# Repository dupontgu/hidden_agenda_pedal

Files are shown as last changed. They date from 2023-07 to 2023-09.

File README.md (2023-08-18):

# Hidden Agenda
 **A multi-effects pedal for your mouse and keyboard!**

 Have you ever wanted to add reverb to your mouse cursor and sending sailing gently accross your screen? Have you ever wished you could emphatically stomp on something to engage caps lock before ripping an angry email to your manager or tweeting at an airline? No? Well, I made this anyways.

 YouTube Thumbnail (https://www.youtube.com/watch?v=4DGEuZlxPWg)

 ## Contents
 * [How it works](#how-it-works) (at a high level)
 * [Full usage instructions](.docs/usage/)
 * [FAQ](.docs/faq/)
 * [Firmware Source Code](firmware/) (and build instructions)
 * [Electronics](hardware/) (schematic/board files)
 * [Enclosure](enclosure/) (CAD/Art)
 * [Alternate Usages](./circuitpython/) (use it as a MIDI controller!!)

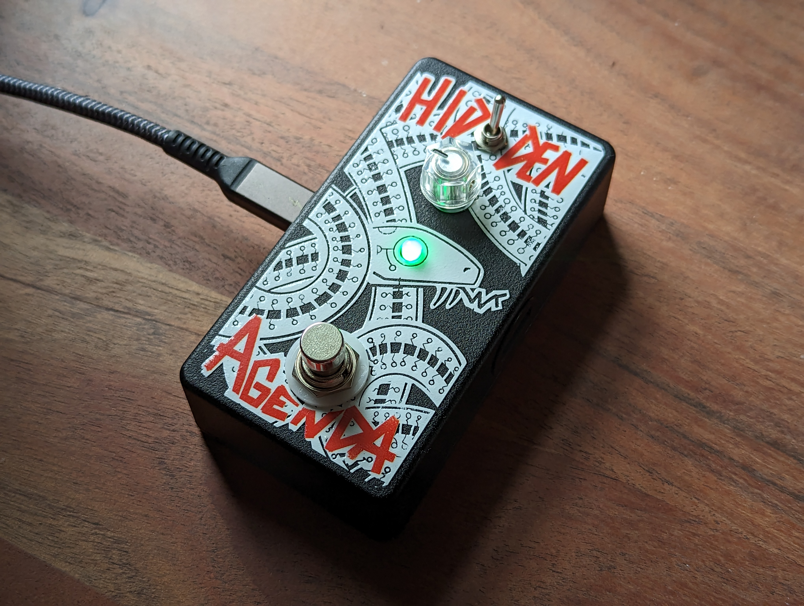
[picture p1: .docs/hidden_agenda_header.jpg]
 [](.docs/hidden_agenda_header.jpg)

 ### Shout-outs
 * Pedal artwork by [Ted Pioli](https://www.tedp.io/)
 * Pedal fabrication from [AmplifyFUN](https://amplifyfun.com/)

 ## How It Works

 The Hidden Agenda works as an HID interceptor. You plug your mouse/keyboard directly into the pedal, and then you plug the pedal into your computer via USB. The software on the pedal analyzes the data coming from the keyboard/mouse, applies some "signal processing" to it, and then forwards the processed data to the computer. When the pedal is off, it simply passes the keyboard/mouse data through without modifying it. It is a standalone unit and should not require any additional software to be installed on your computer - as far as it's concerned, the pedal is just a run-of-the-mill USB keyboard/mouse combo.

 ## What Effects Does It Have?

 The Hidden Agenda currently has 4 unique effects for mouse, and 4 for keyboard. They are mostly inspired by classic audio effects that you might find in a "real" pedal. Each effect has one parameter that can be tweaked with the onboard knob.

 ### Mouse Effects
 #### `1. Reverb`
 Send your cursor flying! This effect adds a bit of momentum to your mouse cursor, so when you stop moving your hand, it will keep going in the direction you were heading. When this effect is active, the knob controls the "length" of the reverb (or, how long it will take to slow down to a stop after you've stopped moving).

 #### `2. Looper`
 Record a gesture with your mouse and play it back on a loop. Hold the right mouse button down to record, move around as you please, and watch loop playback begin as soon as you release. Use the knob to adjust the playback speed of the loop. Turn it all the way up to play it at 2.5X speed, turn it all the way down to play at -2.5X (reversed!).

 #### `3. Distortion / Noise Filter`
 This is a two-in-one effect. Turn _up_ the knob (past halfway), and the pedal will add an increasing amount of random noise to your path of motion. Turn _down_ the knob, and the pedal will apply a low-pass filter to your motion, effectively smoothing it out. 

 #### `4. (Bonus) Crossover`
 Use your mouse as a keyboard! Use the scroll wheel to choose between characters, then tap the right mouse button to move on to the next. Hold the left mouse button + move left to backspace, move right to enter spaces, or move down to "hit" enter. You can also hold the right mouse button and move up/down to scroll through characters. The knob controls the speed at which the characters scroll.

 ### Keyboard Effects
 #### `1. Tremolo`
 Change the "volume" of your typing on a time interval. Imagine an imaginary hand pressing and releasing the shift key for you on a fixed schedule. Turn the knob up to increase the switch rate between upper/lowercase. If you turn the knob _all_ the way up, the effect will constanly force your typing to uppercase, effectively turning the pedal into a foot-powered caps lock button. If you turn the knob all the way down, the pedal will apply rANdOm/SarCaStiC case as you type.

 #### `2. Delay`
 Echo! (echo... echo...). This effect will repeat keystrokes on a time interval for you while it is engaged. The knob is divided into 4 zones, each corresponding to a delay interval time (from left to right: short, short-ish, long-ish, long). Within each zone, the knob controls the "feedback" - AKA the number of repetitions for a given keystroke. The rightmost edge of each zone will set the delay to repeat infinitely for maximum of 6 keys.

 #### `3. Pitch Shift / Harmonizer`
 Maps your keystrokes to... different keystrokes. The knob is divided into 3 sections. In the lowest section, the pedal will simply replace the keys you're pressing with those which are a fixed _"distance"_ away (by their [ascii number](https://www.asciitable.com/)). So if the distance is set to 1, and you press the 'a' key, the pedal will instead type 'b'. If the distance is set to 2, pressing 'a' would yield 'c', etc. You can increase the distance between characters by turning the knob up. As soon as you turn the knob into the second section (about 10 o'clock), the behavior changes slightly. Now, instead of a "pitch shift", this becomes a "harmony" - the orignal key you pressed will be typed, _as well as_ the shifted one. In other words, pressing one key will yield two typed characters. If you turn the knob into the third section (about 2 o'clock), the pedal will type 3 characters for each key you press: your original key character, one that is `n` characters away from that one, and another that is `n` characters away from the second. Think of it as a chord! You can turn up the knob _within_ each section to increase `n`.

 #### `4. (Bonus) Crossover`
 Use your keyboard as a mouse! The arrow keys move the cursor as you'd expect. The `enter` key emulates the mouse's left button. Use the letter keys to send the cursor flying in random directions. Yes, seriously. Modifier keys work as usual.

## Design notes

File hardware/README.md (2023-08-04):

# Hidden Agenda Hardware

Check out an interactive version of this KiCAD project using [KiCanvas](https://kicanvas.org/?github=https://github.com/dupontgu/hidden_agenda_pedal/tree/main/hardware)!!

## BOM

_Most_ of the BOM is available in a [DigiKey parts list](https://www.digikey.com/en/mylists/list/27DUQKO28G), but please read the following notes:
* I have been purchasing the [potentiometer](https://guitarpedalparts.com/products/b5k-16mm-potentiometer-round-shaft-right-angle-pcb-pins), 
[SPDT toggle switch](https://guitarpedalparts.com/products/spdt-on-off-on-toggle-switch-solder-lugs), 
[footswitch](https://guitarpedalparts.com/products/momentary-spdt-foot-switch), and 
[knob cap](https://guitarpedalparts.com/products/small-fluted-knob-clear) on [GuitarPedalParts.com](https://guitarpedalparts.com/)
* For the LED, I use the [WS2812D-F5](https://datasheet.lcsc.com/lcsc/2204181500_Worldsemi-WS2812D-F5_C190565.pdf), which runs on 3.3V power and logic. These are easily sourced on eBay/AliExpress.

## USB Jack Caps

The [USB Jack Caps](./usb_caps_v6.stl) are 3D printed. I use a black, recycled PETG. They push into the side holes on the pedal and stabilize the USB ports (the whole PCB, really). They screw directly into the threaded inserts on the PCB using standard 8mm M3 screws.

## Assembly Notes

* All components are through-hole except for the XIAO RP2040 module.
* The boot button should be installed on the _bottom_ of the board.
* The threaded inserts should also be inserted and soldered from the bottom of the board. For safety, I have been taping over the holes on the top side as well.

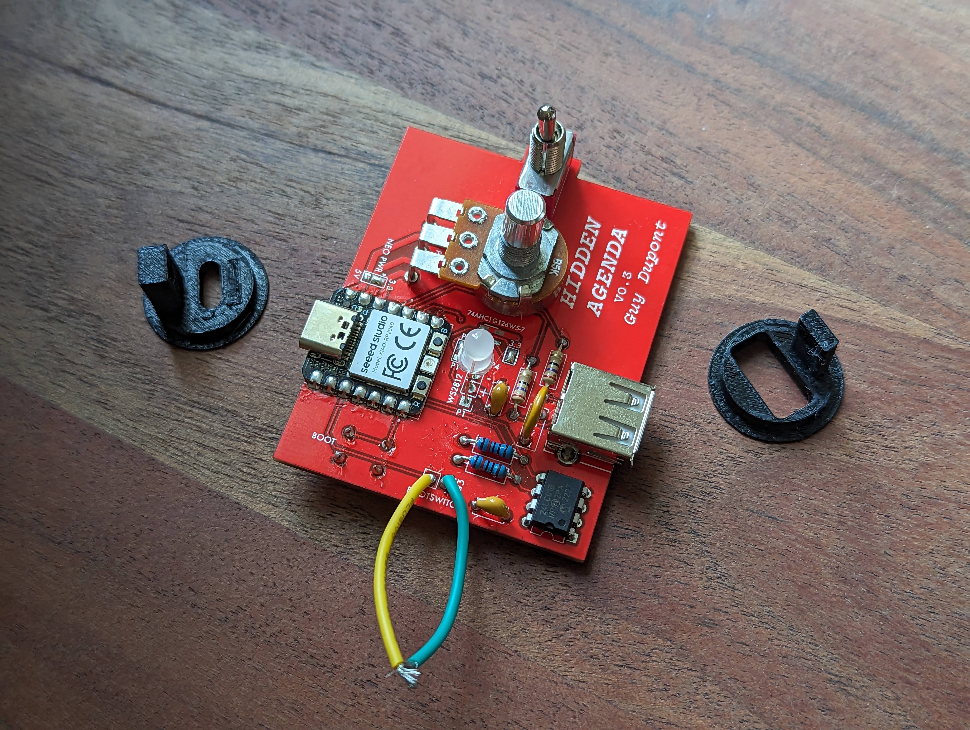
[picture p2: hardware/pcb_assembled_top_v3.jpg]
 [](./pcb_assembled_top_v3.jpg)
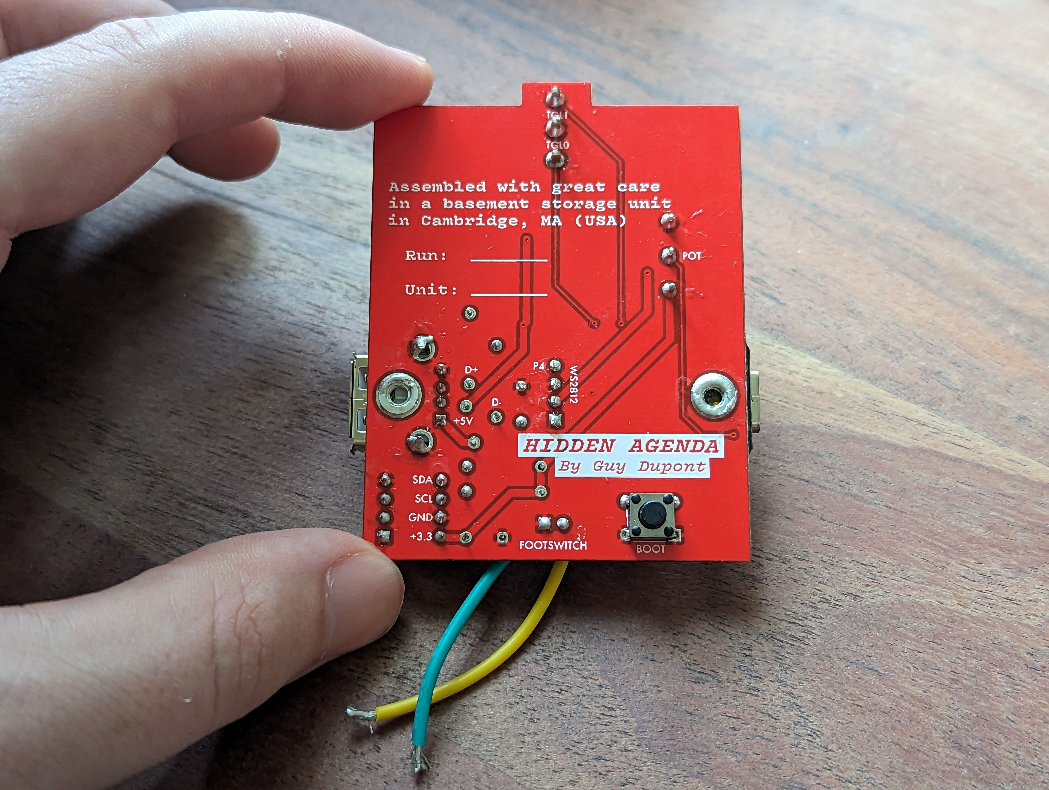
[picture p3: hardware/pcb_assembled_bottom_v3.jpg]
 [](./pcb_assembled_bottom_v3.jpg)

## Schematic

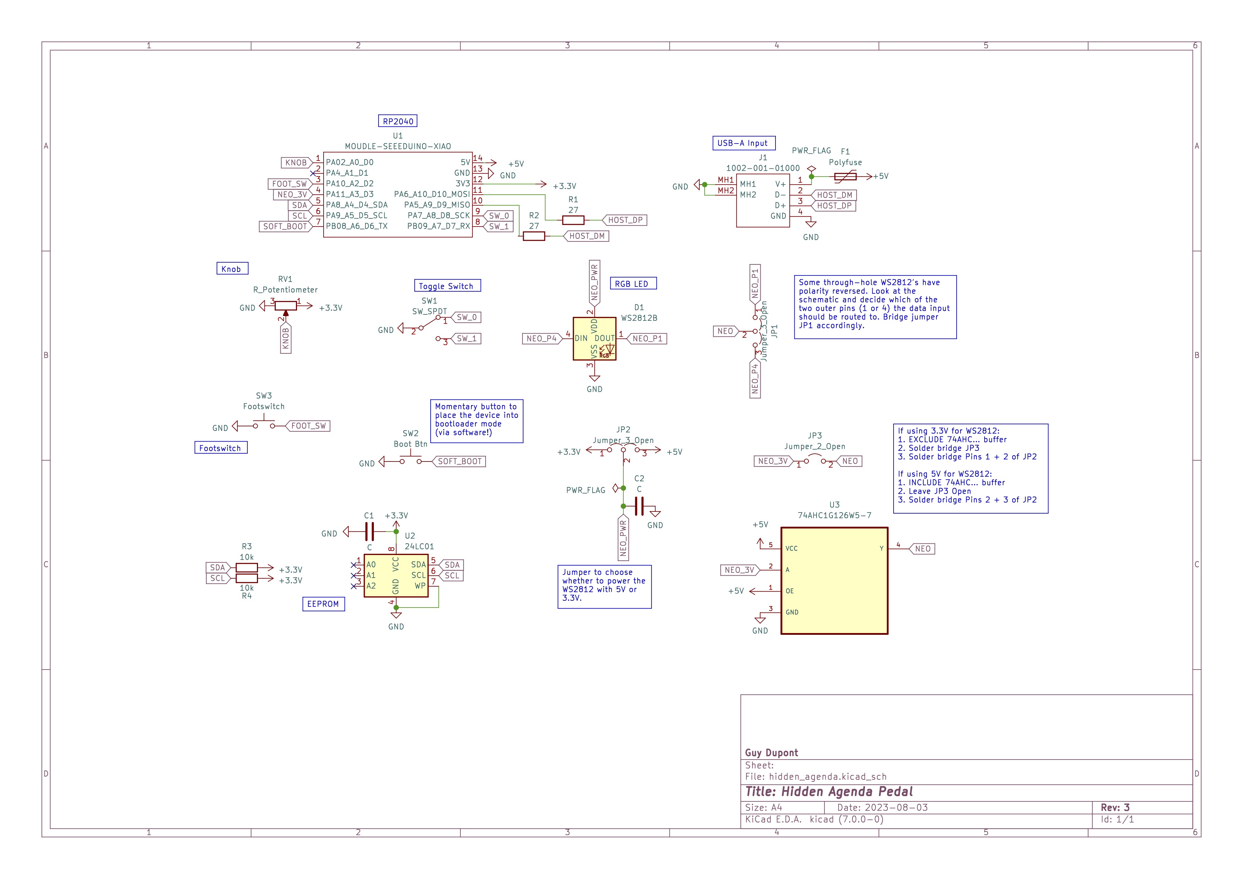
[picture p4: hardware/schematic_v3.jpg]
 [](./schematic_v3.pdf)

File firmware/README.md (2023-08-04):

# Hidden Agenda Firmware
* The pedal is built around the [Raspberry Pi RP2040](https://www.raspberrypi.com/documentation/microcontrollers/rp2040.html) microcontroller.
* The firmware is written in C/C++, using the [Raspberry Pi Pico SDK](https://github.com/raspberrypi/pico-sdk).
* It leverages the [Pico PIO USB](https://github.com/sekigon-gonnoc/Pico-PIO-USB) library, which gives the RP2040 an extra (bit-banged) USB port.
* See the [hardware](../hardware/) section to match up pin numbers.

## Building (Linux)
1. Ensure CMAKE is installed.
1. Clone the Pico SDK and all of its submodules. Export the SDK's path to an environment variable called `PICO_SDK_PATH`.
1. Clone the Pico PIO USB library. Export the library's path to an environment variable called `PICO_PIO_USB_DIR`.
1. Clone this repository, `cd` into the `firmware` directory.
1. Create a build directory and use `cmake` to configure the build:
    ```
    $ mkdir build && cd build
    $ cmake -DPICO_BOARD=ha_board ..
    ```
1. Run the build (you can run this step without the previous ones from here on out):
    ```
    $ make
    ```
1. Find the compiled UF2 file at `build/src/hidden_agenda.uf2` - this can loaded onto the RP2040 while it is in USB bootloader mode.

## Running Tests (Any Platform?)
Code in the [`common`](common) directory should be platform agnostic. Therefore it is possible to run tests against this code on your build machine. The `test` directory will contain an executable that runs default tests. To build this executable, follow the steps above, but add the `TEST` flag when running cmake:
```
cmake -DTEST=ON ..
```
If you've previously built the firmware, you'll have to delete the `CMakeCache.txt` file in the build directory. You'll have to delete this each time you change the `TEST` flag.

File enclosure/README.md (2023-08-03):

# Hidden Agenda Enclosure

 * Pedal artwork by [Ted Pioli](https://www.tedp.io/)
 * Pedal fabrication from [AmplifyFUN](https://amplifyfun.com/)
   * The .psd file in this directory is AmplifyFUN's template file for a 1590B pedal enclosure, populated with the artwork and drill marks for the Hidden Agenda.

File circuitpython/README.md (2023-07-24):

# Hidden Agenda CircuitPython
## Contents
* [How to use the Hidden Agenda as a MIDI controller](./midi_controller/)
* [CircuitPython test script used during board bring-up](./test_script/)

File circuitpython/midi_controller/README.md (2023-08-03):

## Using the Hidden Agenda as a MIDI Controller
**IMPORTANT! This will overwrite the default firmware on your pedal! You will need to [reinstall](../../.docs/usage/README.md#boot-button-updatemodify-the-firmware) it to regain normal functionality.**

The MIDI controller firmware was implemented in [CircuitPython](https://www.circuitpython.org), which makes it super easy to install and customize!

## Installation
1. On your computer, download the latest CircuitPython 8 [UF2 file for the `Seeed Studio XIAO RP2040`](https://circuitpython.org/board/seeeduino_xiao_rp2040/) (That's the microcontroller board that powers this pedal!)
2. Download a recent version of the [Adafruit MIDI library (for Circuitpython 8)](https://github.com/adafruit/Adafruit_CircuitPython_MIDI/releases/download/1.4.16/adafruit-circuitpython-midi-8.x-mpy-1.4.16.zip).
3. Download the `code.py` file from this directory.
4. Unscrew and remove the bottem panel of your pedal.
5. Plug the pedal into your computer using the USB-C port.
6. Press and release the "Boot" button on the inside (bottom) of the pedal. You'll need to unscrew/remove the bottom panel.
7. Observe that the pedal is now mounted as a disk drive on your computer (It will likely be called `RPI-RP2`).
8. Drag/drop the UF2 file you downloaded in step 1 onto the new disk drive. The pedal should reboot and remount as a drive called `CIRCUITPY`.
9. Drag/drop the entire `adafruit_midi` directory from the `lib` directory of the Adafruit MIDI library (step 2) to the `lib` directory on `CIRCUITPY`.
10. Drag/drop the `code.py` file you downloaded in step 3 onto the `CIRCUITPY` drive.
11. As soon as the file is copied over, the pedal should show up as a USB MIDI controller!

## Usage
When the MIDI code from this directory is used, the pedal will send/receive MIDI CC messages:

**`Toggle Switch`**
- Will send value 127 to MIDI CC 110 if the switch is moved to the up position, will send value 0 when it is moved elsewhere.
- Will send value 127 to MIDI CC 111 if the switch is moved to the down position, will send value 0 when it is moved elsewhere.

**`Footswitch`**
- Will send value 127 to MIDI CC 112 when it is pushed down, will send value 0 when it is released. (It is a momentary switch!)

**`Knob`**
- Will send values 0-127 to MIDI CC 113 as it is turned from left to right.

**`LED`**
- By default, the LED will show the status of the 3 parameters above. The red, green, and blue components of the color will represent the states of the toggle/foot switches, and the knob will control the brightness.
- You can override the LED color by sending MIDI CC messages _to_ the pedal from your MIDI host:
  - MIDI CC 110 will change the red component of the LED color.
  - MIDI CC 111 will change the green component of the LED color.
  - MIDI CC 112 will change the blue component of the LED color.

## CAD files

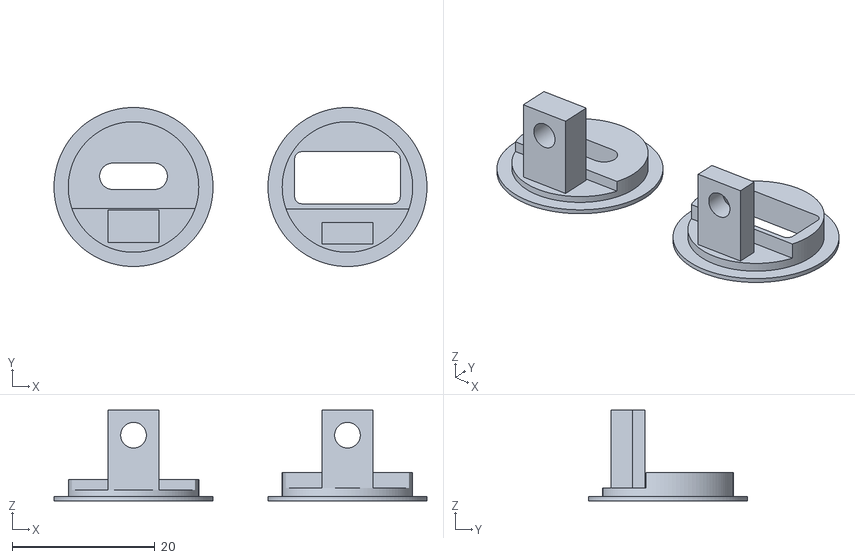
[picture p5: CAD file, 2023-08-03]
hardware/usb_caps_v6.stl
52.3 x 22.3 x 12.7

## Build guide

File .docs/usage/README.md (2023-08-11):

# Hidden Agenda Usage
**Safety note: This is a DIY project, use at your own risk! Do not plug anything other than a USB keyboard or mouse into the USB-A port. Do not use the USB-A port to charge your devices.** 

**Also - this device will perform mouse movements and keystrokes on your behalf! Exit out of any important work before using. I take no responsibility if you accidentally delete something!**

**Also also - the refresh rate of this device's mouse output may not match your mouse's refresh rate. This will lower the performance of any high-speed gaming mice! Maximum output refresh rate is ~170hz, even in passthrough mode.**

## Quick Start
1. Plug the Hidden Agenda into your computer using the USB-C port on the left side of the pedal.
2. Plug your USB mouse or keyboard (or USB dongle for wireless mice/keyboards) into the USB-A port on the right side of the pedal.
3. Flip the toggle switch into the middle position to enter `FX Select` mode. The LED should start blinking.
4. Turn the knob to select your effect - the LED's color will indicate which of the four you have selected.
5. Flip the toggle switch into the "down" position to enter `Latch` mode. The LED should turn off.
6. Hit the footswitch to engage the effect! Your mouse/keyboard should be processed by the effect, and the LED should be providing visual feedback.
7. Dial the knob the change the parameters of the effect, if desired.
8. Hit the footswitch again to disable the effect.

The order of [effects](../../README.md#what-effects-does-it-have) (from knob all-the-way left -> all-the-way right) are:
* Mouse
  1. #FF4000 Reverb
  2. #4000FF Looper
  3. #00FF40 Distortion/Filter
  4. #AA0070 Crossover
* Keyboard
  1. #FF4000 Tremolo 
  2. #4000FF Delay 
  3. #00FF40 Pitch Shift / Harmonizer 
  4. #AA0070 Crossover 

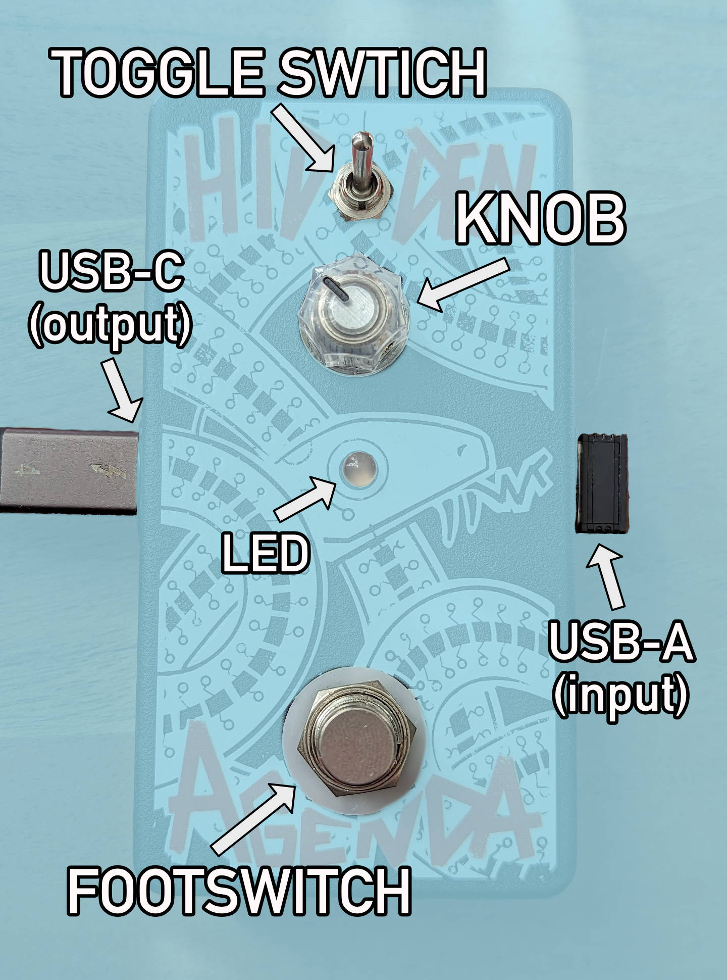
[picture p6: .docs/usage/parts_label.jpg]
 [](./parts_label.jpg)

## More Usage Details
### `Toggle Switch (Mode Select)`
The toggle switch is used to choose between the 3 modes of operation:

#### 1. `Momentary` mode (switch is flipped up)
In this mode, the currently selected effect will only be active _while_ the user is holding down the footswitch. While the footswitch is not pressed, all USB HID events will be passed through to the connected computer, untouched.

#### 2. `FX Select` mode (switch is in middle position)
In this mode, the user can use the knob to change the currently selected effect. The LED will be blinking, and the color represents which FX slot is currently selected. The knob is divided into 4 zones, one for each possible FX slot. In this mode, all USB HID events will be passed through to the computer, untouched.

#### 3. `Latch` mode (switch is in flipped down, towards the knob)
In this mode, the currently selected effect will be _toggled_ on and off by the footswtich. When the user presses the footswitch for the first time, the effect will engage and remain active. When the user presses the footswitch again (following a full release), the effect will disengage and remain inactive until the user presses the footswtich again. While the effect is inactive, all USB HID events will be passed through to the connected computer, untouched.

### `LED`
The RGB LED indicator behaves differently depending on which mode the pedal is in (see above). In `FX Select mode`, it will flash a color slowly to indicate which effect is currently selected. The knob is virtually divided into 4 (roughly) equally sized zones - 1 for each of the FX slots. The default colors for each FX slot 1-4 (from knob all-the-way left -> all-the-way right) are:
1. #FF4000 `Orange-ish`
2. #4000FF `Purple-ish`
3. #00FF40 `Green-ish-blue-ish`
4. #AA0070 `Pink-ish`

**(Note that colors on your computer/phone screen will look slightly different than on the RGB LED)**

While the pedal is in either `Latch` or `Momentary` modes, the LED will show you which effect is currently selected (using the colors above), whether or not the effect is engaged, and a rough indication of what the effect is _doing_ (and/or how it is configured) using patterns of blinking and fading.

In an effort to try to make the device more accessible/less annoying, many of the LEDs properties are configurable. See the [serial console](#the-serial-console) section below. You can:
* Change any/all of the colors associated with the FX slots.
* Change the overall brightness of the LED (this will affect color accuracy).
* Disable all blinking/fading/patterns (the LED will either be on or off depending on state).

### `Boot Button (update/modify the firmware)`
If you want to update the pedal's firmware, upload your own, or explore alternative usages ([such as using it as a MIDI Controller!](../../circuitpython/midi_controller/)), you'll need to use the `boot` button. This button places the pedal into UF2 bootloader mode, which means you can drag and drop a `.uf2` firmware file compiled for the [RP2040 microcontroller](https://en.wikipedia.org/wiki/RP2040) onto it via USB. To find the latest "official" firmware, check out the [releases](https://github.com/dupontgu/hidden_agenda_pedal/releases) page of this repository. To load the firmware:

1. Plug the pedal into your computer using the USB-C port.
2. Flip the pedal over and unscrew/remove the bottom panel.
3. Press the "boot" button on the bottom of the circuit board inside the pedal.
4. Observe that a new disk drive has mounted to your computer, likely called: `RPI-RP2`.
5. Drag and drop your new `.uf2` file onto the drive. When it's done uploading, the pedal will restart with the new firmware running.

#### Additional Notes (Advanced)
* If you want to build your own custom firmware, check out the [hardware docs](../../hardware/) to figure out which pins are being used for what.
* If you don't want to take the back cover off, you can use the [seraial console's boot command](#boot) to programmatically place the pedal into bootloader mode.
* **The `boot` button is NOT hardwared to the RP2040's `BOOTSEL` pin! It is hooked up to a GPIO pin and resetting the RP2040 using a [software call](../../firmware/src/hidden_agenda.cpp#L233)! If you do write custom firmware, you will have to manually copy this functionality.**
* In case you forget to handle ^^, there is a hardwired `BOOTSEL` button on the _top_ of the circuit board. It is on the XIAO module, labeled: `B`. Hold it while power-cycling the board to enter bootloader mode.

## The Serial Console
In addition to acting as a USB keyboard/house, the Hidden Agenda can act as a USB serial device. You can connect to the serial console using a terminal application on your computer. While connected, the pedal will emit log messages and can receive commands to change certain settings. 

If you don't know how to "talk" to a USB serial device, I highly recommend Adafruit's tutorials for [Windows](https://learn.adafruit.com/welcome-to-circuitpython/advanced-serial-console-on-windows), [macOS](https://learn.adafruit.com/welcome-to-circuitpython/advanced-serial-console-on-mac-and-linux), and [Linux](https://learn.adafruit.com/welcome-to-circuitpython/advanced-serial-console-on-linux). Ensure that your pedal is plugged into your computer using the USB-C port before attempting to connect!

All supported commands are documented below. Each command is sent to the device by first typing `cmd:`, then the name of the setting you are trying to change, then the value(s) you'd like to set, then hitting enter. The items should be separated by colons.

### `boot`
* Resets the device into USB bootloader mode so you can update/change the firmware.
* (No parameters)
* example: `cmd:boot`

### `reset`
* Sets all following settings to their default hardcoded values
* (No parameters)
* example: `cmd:reset`

### `brightness`
* Sets the maximum brightness of the onboard LED, as a percentage
* parameter: an integer between 1-100 (inclusive) representing the brightness percentage
* defaults to 70%
* example: `cmd:brightness:80` (sets the maximum brightness to 80%)

### `flash`
* Sets whether or not the onboard LED should blink/flash/change brightness while in use, or remain static.
* parameter: either `on` or `off`
* defaults to `on`
* example: `cmd:flash:off` (turns LED flashing off - it will glow a solid color when in FX Select mode, and while the effect is engaged)

### `set_color`
* Sets the LED color for a given FX slot.
* parameter 1: index of the FX slot you want to change the color of (1-4)
* parameter 2: 24-bit [hex RGB color](https://htmlcolorcodes.com/)
* default values are: `{0xFF4000, 0x4000FF, 0x00FF40, 0xAA0070}`
* example: `cmd:set_color:1:FF0000` (sets the the color for the first FX slot to red)

### `raw_hid`
* Sets whether or not the pedal should log all _incoming_ HID messages from connected keyboards/mice (as hex strings).
* parameter: either `on` or `off`
* defaults to `off`
* example: `cmd:raw_hid:on` (turns on HID logging - all incoming HID messages will be printed to the serial console)

### `invert_foot`
* Sets whether or not to invert the digial reading from the pin connected to the footswitch. Sometimes I wire it backwards, oops!
* parameter: either `on` or `off`
* defaults to `off`
* example: `cmd:invert_foot:on` (enables the inversion of the footswitch, which should read as 0 when untouched, 1 when held down)

### `m` (mouse command)
* Sends a hardcoded mouse "report" through the pedal's processing pipeline.
* Can be used to script mouse movements and clicks from your computer.
* parameter: 24 bit hex value, where the leftmost byte represents clicked buttons, the middle byte represents movement on the x axis (signed), and the lowest byte represents movement on the y axis (signed).
* example: `cmd:m:0x0103FF` (fires off a mouse report that says the mouse has its left button pressed, moved 3 "pixels" to the left, and moved 1 "pixel" towards the top of the screen)

### `m_speed` (mouse command)
* Sets a mouse speed adjustment factor, from 0.5X to 1.5X.
* parameter: integer between 1 and 5 (inclusive). `1` sets your mouse to half speed, `5` sets to 1.5X speed.
* defaults to `2`
* example: `cmd:m_speed:3` (sets mouse speed to 1.25X)

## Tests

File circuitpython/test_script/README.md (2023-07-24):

# Test Script
This directory contains a reference script - written in CircuitPython - that I use to verify the hardware is setup correctly before installing the "production" firmware. If you want to run it, follow the instructions to install CircuitPython in the [MIDI Controller docs](../midi_controller/README.md#installation).

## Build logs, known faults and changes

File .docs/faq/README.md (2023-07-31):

# Hidden Agenda FAQ
**(Written before anyone's asked any questions, but you get the idea)**

### `Will it work with *my* keyboard or mouse?`
If you have a standard USB keyboard or mouse, it _should_ work, but I make **no** promises. USB is complicated, and this is not my full time job. I have tested with as many mice/keebs as I could get my hands on, but I will not be buying any more to test with. It's just not practical. If you find yourself with one of these pedals and are seeing weird behavior, please email me or create a GitHub issue here and provide as much info as you can. Again - I make no promises, but if I can find time to help debug I will.

### `Will it work with a USB hub?`
In _theory_, yes, with caveats. **I have not tried this yet, so absolutely no guarentees!**
* The output current provided by the USB-A port is limited by a resettable fuse. The limit is not very high. If you're going to try a hub, use a powered one.
* You can only have one FX slot selected, for both keyboard AND mouse. So if you have both devices connected, and you want to use the mouse effect in slot 1, you have no choice but to use the keyboard effect in slot 1 simultaneously.
* Similarly, both effects are either engaged or disengaged at the same time, and the parameter value provided by the knob will be the same for both effects as well.

### `Can I use a combination keyboard/mouse?`
* See all the points for the [USB hub question](#will-it-work-with-a-usb-hub) above!
* I actually have had luck with one of these cheap wireless devices from MicroCenter. Both keyboard and mouse work fine. HOWEVER! The USB HID reports are a bit different from those provided from plain old keyboards/mice. There is a [chunk of code](../../firmware/src/hidden_agenda.cpp#L477) that handles the difference, but I truly have no idea if other combination devices will send the data in a similar manner. Give it a try! If things act weird, let me know in a GitHub issue. But please don't say I didn't warn you, and I make no promises in terms of providing a fix.

### `Can I customize the pedal?`
* Out of the "box", there are a few settings you can change using the [`serial console`](../usage/README.md#the-serial-console). I am open to adding more configurable settings, so feel free to leave suggestions!
* If you want to add/change effects (and are comfy with C/C++), the fx [base classes](../../firmware/common/include/custom_hid.hpp) and simple [passthrough](../../firmware/common/include/mouse_fx/mouse_fx_passthrough.hpp) implementations are a good starting point.
* You can also load [CircuitPython](../../circuitpython/) onto the pedal and use it as a MIDI controller.

### `WHY?`
The idea presented itself to me in the middle of the night. My daughter was ~4 months old at the time - nobody in the house was sleeping, nobody was thinking straight. I was watching a [JHS](https://www.youtube.com/channel/UCjfbkA4jJkJY5g0wbjuoZWA) YouTube video, thinking: "damn, it's gotta feel so good to _stomp_ on that overdrive pedal right before ripping a guitar solo in front of a bunch of screaming fans." The next thought was something like: "Wouldn't it _also_ feel good to stomp on something before typing up an angry email?" I giggled to myself for an extended period of time and starting ordering parts on my phone.

Despite the admittedly silly nature of the device, there are some aspects of it that keep me genuinely excited. I think the idea of having dedicated, modular hardware that processes streams of _data_ (vs. audio) is one worth exploring further. And I hope you'll find that -- in certain configurations -- some of these effects might actually be... useful? Offloading work from hands to feet might be a game changer for some. My friends at Adafruit have recently pointed out how [adding a filter to mouse movement](https://www.youtube.com/watch?v=4SYdXDB0t4M) might help folks who can't move as smoothly as the average computer user. If you can think of any usecases for this pedal that actually help you in some way (or suggestions for features that would make it _more_ helpful to you), PLEASE let me know. I would love to hear from you.

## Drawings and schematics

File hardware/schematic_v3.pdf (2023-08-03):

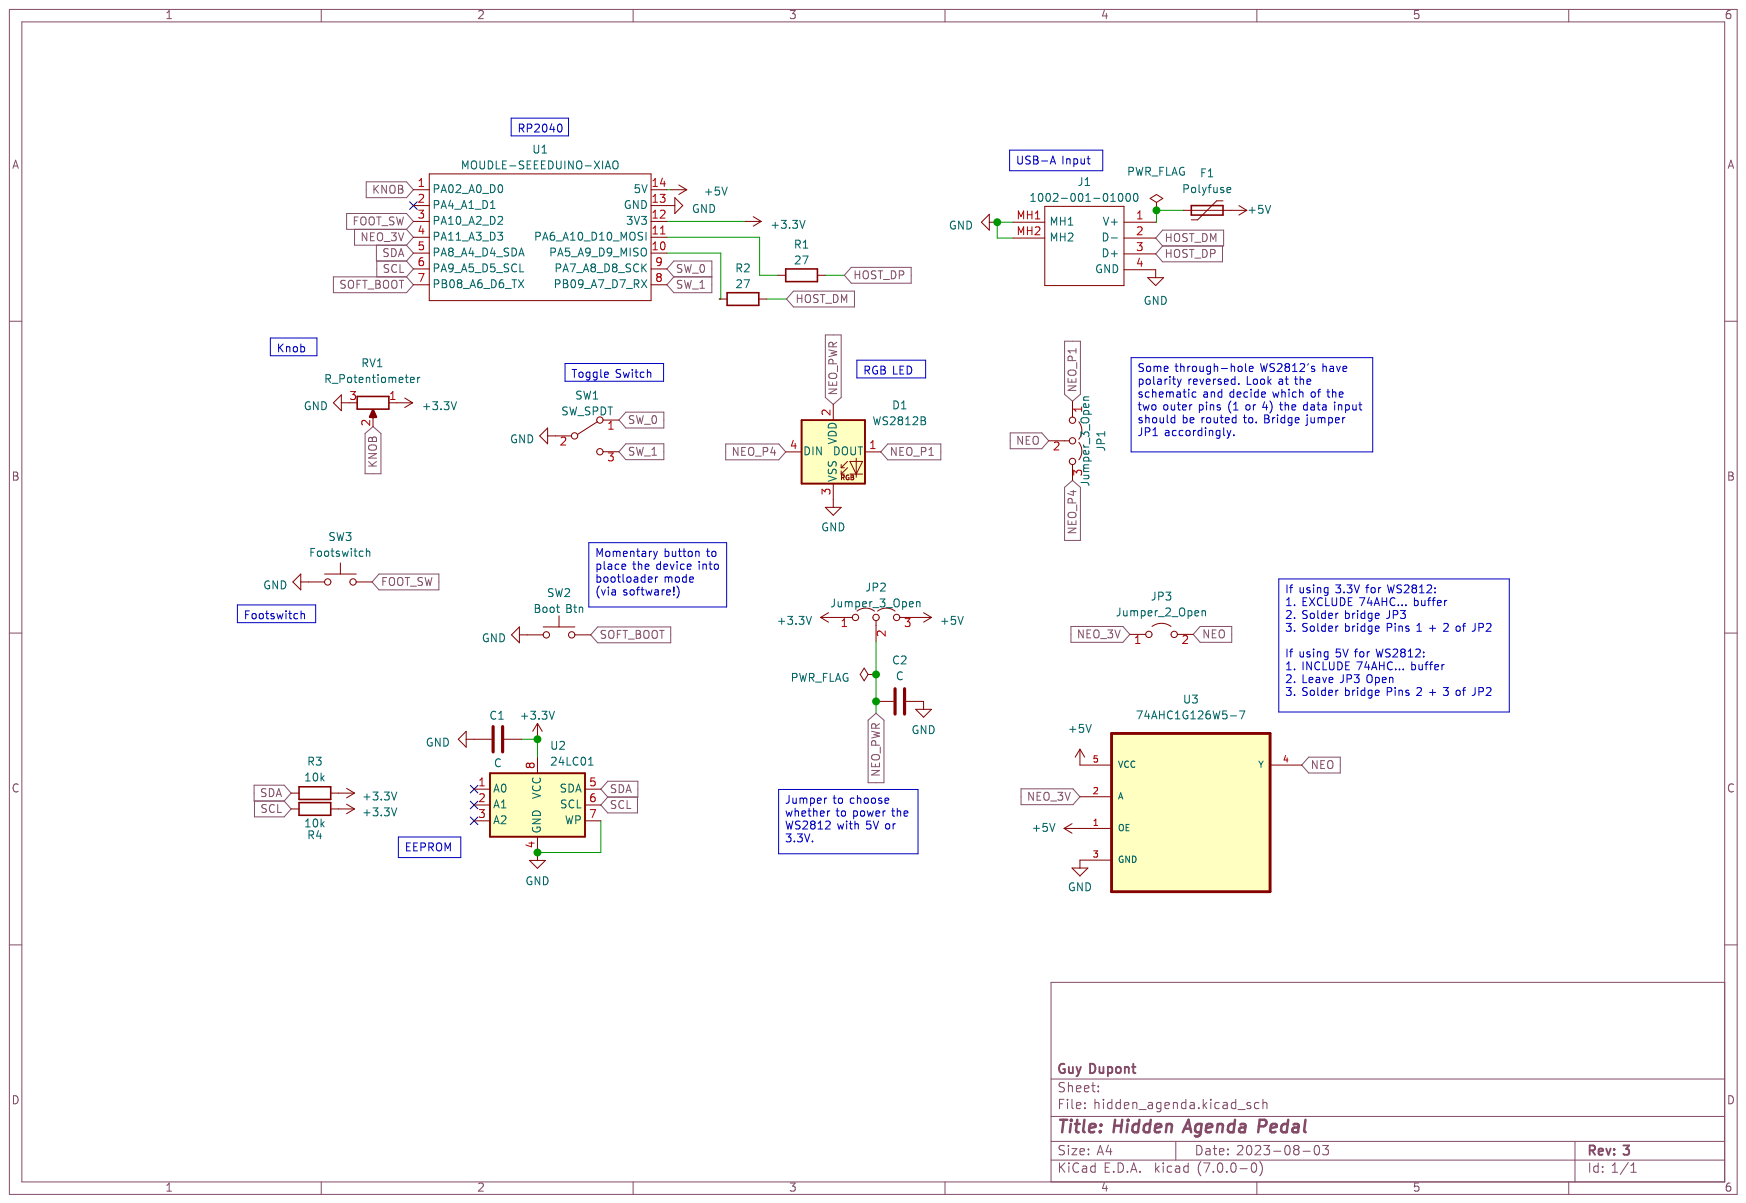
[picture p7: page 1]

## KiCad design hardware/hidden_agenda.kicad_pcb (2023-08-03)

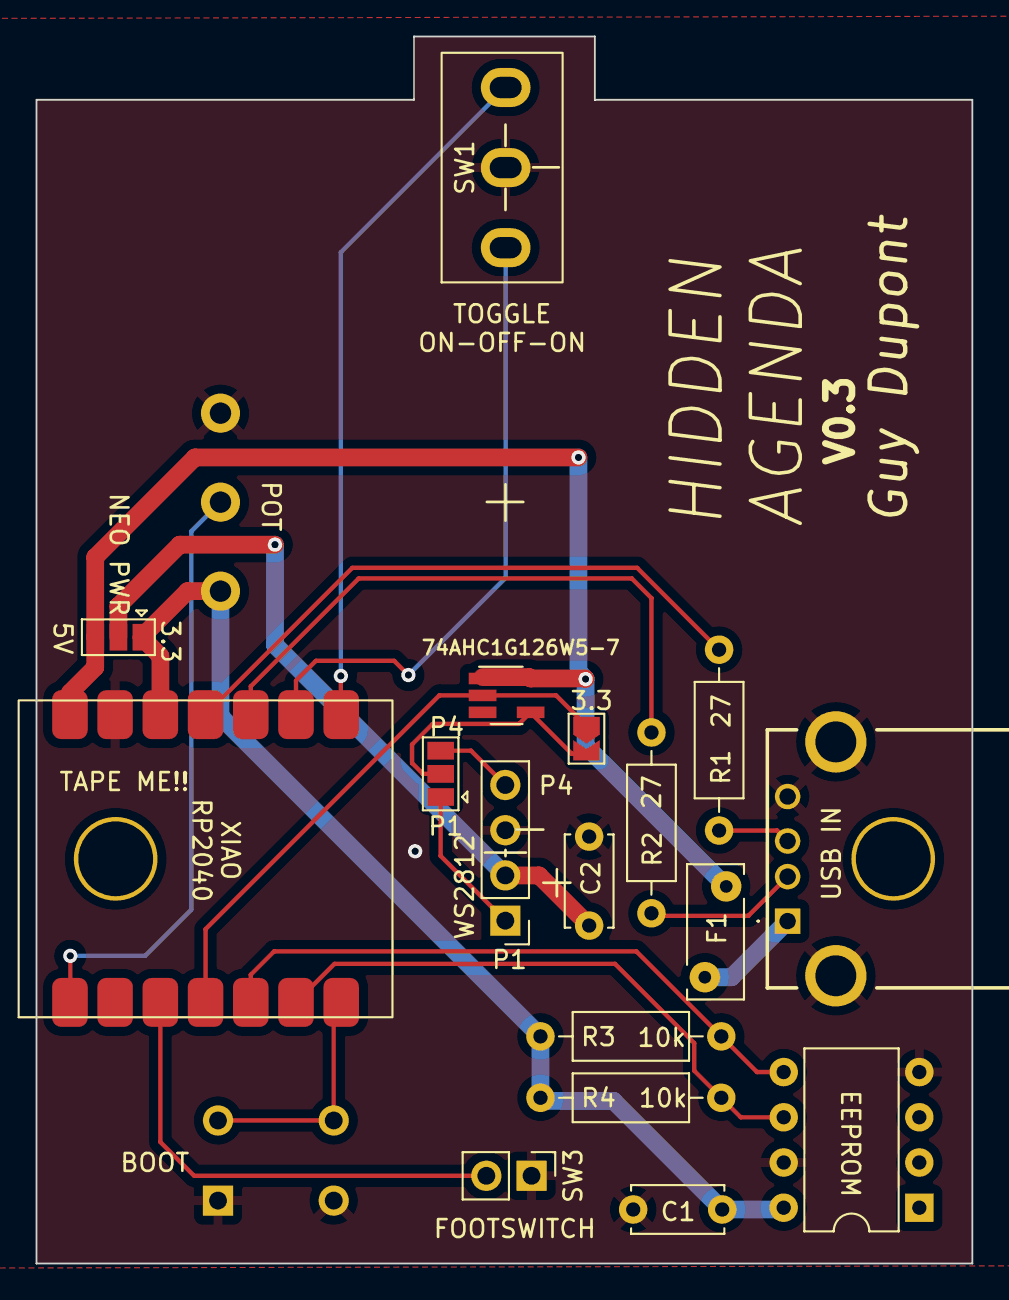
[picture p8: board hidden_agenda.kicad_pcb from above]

Board: 2 copper layers, 52.6 x 68.9 mm, 19 parts (1 on the bottom side), 20 nets.

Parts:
C1, C2: C; C_Disc_D5.0mm_W2.5mm_P5.00mm
D1: WS2812B; PinHeader_1x04_P2.54mm_Vertical
F1: Polyfuse; Fuse_Bourns_MF-RHT050
J1: 1002-001-01000; 100200101000
JP1, JP2: Jumper_3_Open; SolderJumper-3_P1.3mm_Open_Pad1.0x1.5mm
JP3: Jumper_2_Open; SolderJumper-2_P1.3mm_Open_TrianglePad1.0x1.5mm
R1, R2: 27; R_Axial_DIN0207_L6.3mm_D2.5mm_P10.16mm_Horizontal
R3, R4: 10k; R_Axial_DIN0207_L6.3mm_D2.5mm_P10.16mm_Horizontal
RV1: R_Potentiometer; B5K_Potentiometer
SW1: SW_SPDT; GuitarPedalParts_SPDT
SW2: Boot Btn; SW_TH_Tactile_Omron_B3F-10xx
SW3: Footswitch; PinHeader_1x02_P2.54mm_Vertical
U1: MOUDLE-SEEEDUINO-XIAO; MOUDLE14P-SMD-2.54-21X17.8MM
U2: 24LC01; DIP-8_W7.62mm
U3: 74AHC1G126W5-7; SOT-23-5_HandSoldering

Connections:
+3.3V: C1.1, JP2.1 (A), R3.2, R4.2, RV1.1, U1.12 (3V3), U2.8 (VCC)
+5V: F1.2, JP2.3 (B), U1.14 (5V), U3.1 (OE), U3.5 (VCC)
FOOT_SW: SW3.2, U1.3 (PA10_A2_D2)
GND: C1.2, C2.2, D1.3 (VSS), J1.4 (GND), J1.MH1, J1.MH2, RV1.3, SW1.2 (B), SW2.1, SW3.1, U1.13 (GND), U2.4 (GND), U2.7 (WP), U3.3 (GND)
HOST_DM: J1.2 (D-), R2.2
HOST_DP: J1.3 (D+), R1.2
KNOB: RV1.2, U1.1 (PA02_A0_D0)
NEO: JP1.2 (C), JP3.2 (B), U3.4 (Y)
NEO_3V: JP3.1 (A), U1.4 (PA11_A3_D3), U3.2 (A)
NEO_P1: D1.1 (DOUT), JP1.1 (A)
NEO_P4: D1.4 (DIN), JP1.3 (B)
NEO_PWR: C2.1, D1.2 (VDD), JP2.2 (C)
unnamed: F1.1, J1.1 (V+)
unnamed: R2.1, U1.10 (PA5_A9_D9_MISO)
unnamed: R1.1, U1.11 (PA6_A10_D10_MOSI)
SCL: R4.1, U1.6 (PA9_A5_D5_SCL), U2.6 (SCL)
SDA: R3.1, U1.5 (PA8_A4_D4_SDA), U2.5 (SDA)
SOFT_BOOT: SW2.2, U1.7 (PB08_A6_D6_TX)
SW_0: SW1.1 (A), U1.9 (PA7_A8_D8_SCK)
SW_1: SW1.3 (C), U1.8 (PB09_A7_D7_RX)

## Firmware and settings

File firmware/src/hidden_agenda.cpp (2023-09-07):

/*
 * The MIT License (MIT)
 *
 * Copyright (c) 2023 Guy Dupont
 *
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
 */

#include <stdarg.h>
#include <stdio.h>
#include <stdlib.h>
#include <string.h>

#include <cmath>

#include "bsp/board.h"
#include "hardware/adc.h"
#include "hardware/watchdog.h"
#include "i2c_persistence.hpp"
#include "kbd_fx/kbd_fx_delay.hpp"
#include "kbd_fx/kbd_fx_harmonizer.hpp"
#include "kbd_fx/kbd_fx_passthrough.hpp"
#include "kbd_fx/kbd_fx_tremolo.hpp"
#include "kbd_fx/kbd_fx_xover.hpp"
#include "mouse_fx/mouse_fx_fuzz.hpp"
#include "mouse_fx/mouse_fx_looper.hpp"
#include "mouse_fx/mouse_fx_passthrough.hpp"
#include "mouse_fx/mouse_fx_reverb.hpp"
#include "mouse_fx/mouse_fx_xover.hpp"
#include "pico/multicore.h"
#include "pico/stdlib.h"
#include "pico/time.h"
#include "pio_usb.h"
#include "repl.hpp"
#include "tud_hid_output.hpp"
#include "tusb.h"
#include "usb_descriptors.h"
#include "util.h"
#include "ws2812.pio.h"

#define GENERIC_DESKTOP_USAGE_PAGE 0x01
#define USAGE_MOUSE 0x02
#define USAGE_KEYBOARD 0x06

#define MS_SINCE_BOOT to_ms_since_boot(get_absolute_time())
#define SOFT_BOOT_BTN_GPIO 0
#define PIX_DATA_GPIO 29
#define FOOT_SW_GPIO 28
#define TOGGLE_1_GPIO 2
#define TOGGLE_2_GPIO 1
#define KNOB_ADC_GPIO 26

#define PIX_PIO pio0
#define PIX_PIO_SM 2

#define MAX_FX 4
#define MAX_REPORT 4

#define SW_MODE_SET 0
#define SW_MODE_MOM 1
#define SW_MODE_LATCH 2

#define ADC_DEAD_ZONE 0.015f

#define LOG_BUFFER_SIZE 1024
#define NO_OFFICIAL_INSTANCE 0xFF

static struct {
  uint8_t report_count;
  tuh_hid_report_info_t report_info[MAX_REPORT];
} hid_info[CFG_TUH_HID];

static void process_sidedoor_mouse_report(uint8_t buttons, int8_t x, int8_t y);

I2cPersistence settings;
TinyHIDOutput hid_output(process_sidedoor_mouse_report);
Repl repl(&settings, &hid_output);
MouseFuzz mouse_fuzz(&hid_output);
MouseLooper mouse_looper(&hid_output);
MousePassthrough mouse_passthrough(&hid_output);
MouseReverb mouse_reverb(&hid_output);
MouseXOver mouse_xover(&hid_output);
KeyboardTremolo keyboard_tremolo(&hid_output);
KeyboardXOver keyboard_xover(&hid_output);
KeyboardPassthrough keyboard_passthrough(&hid_output);
KeyboardDelay keyboard_delay(&hid_output);
KeyboardHarmonizer keyboard_harmonizer(&hid_output);
// LAST FX (at index MAX_FX) should always be passthrough! This is what gets run
// when pedal is "off"
static IMouseFx* mouse_fx[] = {&mouse_reverb, &mouse_looper, &mouse_fuzz,
                               &mouse_xover, &mouse_passthrough};
static IKeyboardFx* keyboard_fx[] = {&keyboard_tremolo, &keyboard_delay,
                                     &keyboard_harmonizer, &keyboard_xover,
                                     &keyboard_passthrough};
static uint8_t active_device_type = HID_ITF_PROTOCOL_KEYBOARD;
static bool fx_enabled = false;
static uint8_t active_sw_mode = SW_MODE_SET;
static bool use_increased_dead_zone = 0;

static char log_buffer[LOG_BUFFER_SIZE];
static size_t log_write_head = 0;
static size_t log_read_head = 0;

static char cdc_read_buffer[LOG_BUFFER_SIZE];
static size_t cdc_read_head = 0;
static ha_mouse_report_t pending_mouse_report;
static bool mouse_report_ready = false;

static uint8_t official_mouse_instance = NO_OFFICIAL_INSTANCE;
static uint8_t official_kb_instance = NO_OFFICIAL_INSTANCE;

void log_line(const char* format, ...) {
  // shouldn't happen, but throw it away to be safe
  if (log_write_head >= (LOG_BUFFER_SIZE - 255)) {
    return;
  }
  va_list args;
  va_start(args, format);
  log_write_head += vsnprintf(log_buffer + log_write_head, 253, format, args);
  log_buffer[log_write_head] = '\r';
  log_buffer[log_write_head + 1] = '\n';
  log_buffer[log_write_head + 2] = 0;
  log_buffer[log_write_head + 3] = 0;
  log_write_head += 3;

  va_end(args);
}

void flush_log() {
  if (log_write_head) {
    size_t len = strlen(log_buffer + log_read_head);
    if (len > 0) {
      tud_cdc_write(log_buffer + log_read_head, len);
      tud_cdc_write_flush();
      log_read_head += len + 1;
    } else {
      log_read_head = 0;
      log_write_head = 0;
    }
  }
}

void process_cdc_input() {
  if (cdc_read_head) {
    if (cdc_read_buffer[cdc_read_head - 1] == '\r') {
      cdc_read_buffer[cdc_read_head - 1] = 0;
      repl.process(cdc_read_buffer);
      cdc_read_head = 0;
    }
    tud_cdc_read_flush();
  }
}

void on_fx_param_tweaked(float percentage) {
  uint8_t active_slot = settings.getActiveFxSlot();
  mouse_fx[active_slot]->update_parameter(percentage);
  keyboard_fx[active_slot]->update_parameter(percentage);
}

inline float read_pot() {
  // expand range so we'll def get 0 and 1 on the ends
  float adc = ((((float)adc_read() / 4096.0f) * 1.03f) - 0.015);
  // clamp to range 0..1
  adc = adc < 0.0f ? 0.0f : (adc > 1.0f ? 1.0f : adc);
  return adc;
}

void update_from_pot() {
  static float previous_adc_reading = read_pot();
  float adc = read_pot();
  float delta = previous_adc_reading - adc;
  float dead_zone = use_increased_dead_zone ? ADC_DEAD_ZONE * 4 : ADC_DEAD_ZONE;
  // is there a less terrible way to write this? perhaps.
  if (!(adc == 1.0f && previous_adc_reading != 1.0f) &&
      !(adc == 0.0f && previous_adc_reading != 0.0f) && delta < dead_zone &&
      delta > -dead_zone) {
    return;
  }
  use_increased_dead_zone = 0;
  previous_adc_reading = adc;
  if (active_sw_mode != SW_MODE_SET) {
    on_fx_param_tweaked(adc);
  } else {
    uint8_t slot = adc * MAX_FX;
    if (slot == MAX_FX) slot--;
    uint8_t active_fx_slot = settings.getActiveFxSlot();
    if (slot != active_fx_slot) {
      log_line("fx slot: %u", slot);
      uint32_t time_ms = MS_SINCE_BOOT;
      mouse_fx[active_fx_slot]->deinit();
      mouse_fx[slot]->initialize(time_ms, adc);
      keyboard_fx[active_fx_slot]->deinit();
      keyboard_fx[slot]->initialize(time_ms, adc);
      settings.setActiveFxSlot(slot);
    }
  }
}

void read_foot_switch() {
  static bool previous_foot_sw_value = 0;
  bool current_val = gpio_get(FOOT_SW_GPIO);
  current_val = settings.shouldInvertFootswitch() ? !current_val : current_val;
  if (current_val == previous_foot_sw_value) {
    return;
  }
  log_line("foot switch: %u", (uint8_t)current_val);
  previous_foot_sw_value = current_val;
  if (active_sw_mode == SW_MODE_LATCH && current_val) {
    fx_enabled = !fx_enabled;
  } else if (active_sw_mode == SW_MODE_MOM) {
    fx_enabled = current_val;
  }
}

void read_toggle_switch() {
  uint8_t current_val = (gpio_get(TOGGLE_1_GPIO) ? 0 : 0b01) |
                        (gpio_get(TOGGLE_2_GPIO) ? 0 : 0b10);
  if (current_val == active_sw_mode) {
    return;
  }
  active_sw_mode = current_val;
  log_line("toggle switch: %u", current_val);
  // if we're switching modes, disable the fx and make the knob less sensitive
  fx_enabled = false;
  use_increased_dead_zone = 1;
}

void init_soft_boot() {
  gpio_init(SOFT_BOOT_BTN_GPIO);
  gpio_set_dir(SOFT_BOOT_BTN_GPIO, GPIO_IN);
  gpio_pull_up(SOFT_BOOT_BTN_GPIO);
  gpio_set_irq_enabled_with_callback(SOFT_BOOT_BTN_GPIO, GPIO_IRQ_EDGE_FALL,
                                     true, &reboot_to_uf2);
}

void init_pix() {
  uint offset = pio_add_program(PIX_PIO, &ws2812_program);

  ws2812_program_init(PIX_PIO, PIX_PIO_SM, offset, PIX_DATA_GPIO, 800000,
                      false);
}

void init_io() {
  gpio_init(TOGGLE_1_GPIO);
  gpio_set_dir(TOGGLE_1_GPIO, GPIO_IN);
  gpio_pull_up(TOGGLE_1_GPIO);

  gpio_init(TOGGLE_2_GPIO);
  gpio_set_dir(TOGGLE_2_GPIO, GPIO_IN);
  gpio_pull_up(TOGGLE_2_GPIO);

  gpio_init(FOOT_SW_GPIO);
  gpio_set_dir(FOOT_SW_GPIO, GPIO_IN);
  gpio_pull_up(FOOT_SW_GPIO);

  adc_init();
  adc_gpio_init(KNOB_ADC_GPIO);
  adc_select_input(0);
}

static inline void set_pixel(uint32_t pixel_grb) {
  pio_sm_put_blocking(PIX_PIO, PIX_PIO_SM, pixel_grb << 8u);
}

void led_task(uint32_t time_ms) {
  static uint32_t frame_of_last_pix_update = 0;
  uint32_t frame = time_ms / 30;
  if (frame == frame_of_last_pix_update) {
    return;
  }
  frame_of_last_pix_update = frame;
  uint32_t color = 0;
  uint8_t active_fx_slot = settings.getActiveFxSlot();
  if (active_sw_mode == SW_MODE_SET) {
    // blink if flashing is enabled
    if (frame % 20 > 10 && settings.isFlashingEnabled()) {
      color = 0;
    } else if (active_device_type == HID_ITF_PROTOCOL_KEYBOARD) {
      color = keyboard_fx[active_fx_slot]->get_indicator_color();
    } else {
      color = mouse_fx[active_fx_slot]->get_indicator_color();
    }
  } else if (fx_enabled) {
    IFx* fx = mouse_fx[active_fx_slot];
    if (active_device_type == HID_ITF_PROTOCOL_KEYBOARD) {
      fx = keyboard_fx[active_fx_slot];
    }
    if (settings.isFlashingEnabled()) {
      color = fx->get_current_pixel_value(time_ms);
    } else {
      color = fx->get_indicator_color();
    }
  }
  set_pixel(color_at_brightness(color, settings.getLedBrightness()));
}

void io_task(uint32_t time_ms) {
  static uint32_t frame_of_last_io_update = 0;
  uint32_t frame = time_ms / 20;
  if (frame == frame_of_last_io_update) {
    return;
  }
  frame_of_last_io_update = frame;
  read_toggle_switch();
  read_foot_switch();
  update_from_pot();
}

void fx_task(uint32_t time_ms) {
  if (fx_enabled) {
    uint8_t active_slot = settings.getActiveFxSlot();
    mouse_fx[active_slot]->tick(time_ms);
    keyboard_fx[active_slot]->tick(time_ms);
  }
}

void mouse_task(uint32_t time_ms) {
  static uint32_t last_report = 0;
  static uint8_t cached_speed_level = 0xFF;
  static float cached_speed = 1.0f;
  if (time_ms - last_report < 6 || !mouse_report_ready) return;
  ha_mouse_report_t* r = &pending_mouse_report;
  mouse_report_ready = false;
  last_report = time_ms;
  if (cached_speed_level != settings.getMouseSpeedLevel()) {
    cached_speed_level = settings.getMouseSpeedLevel();
    cached_speed = (cached_speed_level * 0.25f) + 0.5f;
  }
  uint8_t slot = fx_enabled ? settings.getActiveFxSlot() : MAX_FX;
  r->x = (int8_t)roundf((float)r->x * cached_speed);
  r->y = (int8_t)roundf((float)r->y * cached_speed);
  mouse_fx[slot]->process_mouse_report(r, time_ms);
}

void refresh_settings() {
  settings.initialize();
  for (size_t i = 0; i < MAX_FX; i++) {
    uint32_t color = settings.getLedColor(i);
    mouse_fx[i]->set_indicator_color(color);
    keyboard_fx[i]->set_indicator_color(color);
  }
}

void core1_main() {
  sleep_ms(150);

  // Use tuh_configure() to pass pio configuration to the host stack
  // Note: tuh_configure() must be called before
  pio_usb_configuration_t pio_cfg = PIO_USB_DEFAULT_CONFIG;
  pio_cfg.pin_dp = 3;
  tuh_configure(1, TUH_CFGID_RPI_PIO_USB_CONFIGURATION, &pio_cfg);

  // To run USB SOF interrupt in core1, init host stack for pio_usb (roothub
  // port1) on core1
  tuh_init(1);

  while (true) {
    tuh_task();  // tinyusb host task
  }
}

/*------------- MAIN -------------*/
int main(void) {
  // init device stack on configured roothub port
  set_sys_clock_khz(120000, true);

  init_soft_boot();
  watchdog_enable(300, 1);
  multicore_reset_core1();
  // all USB task run in core1
  multicore_launch_core1(core1_main);

  tud_init(BOARD_TUD_RHPORT);
  init_pix();
  init_io();
  refresh_settings();

  float param_value = read_pot();
  uint32_t now = MS_SINCE_BOOT;
  uint8_t active_slot = settings.getActiveFxSlot();
  mouse_fx[active_slot]->initialize(now, param_value);
  keyboard_fx[active_slot]->initialize(now, param_value);

  while (1) {
    uint32_t time_ms = MS_SINCE_BOOT;
    led_task(time_ms);
    io_task(time_ms);
    fx_task(time_ms);
    mouse_task(time_ms);
    flush_log();
    tud_task();  // tinyusb device task
    process_cdc_input();
    watchdog_update();
  }

  return 0;
}

//--------------------------------------------------------------------+
// Host HID
//--------------------------------------------------------------------+

// Invoked when device with hid interface is mounted
// Report descriptor is also available for use.
// tuh_hid_parse_report_descriptor() can be used to parse common/simple enough
// descriptor. Note: if report descriptor length > CFG_TUH_ENUMERATION_BUFSIZE,
// it will be skipped therefore report_desc = NULL, desc_len = 0
void tuh_hid_mount_cb(uint8_t dev_addr, uint8_t instance,
                      uint8_t const* desc_report, uint16_t desc_len) {
  // Interface protocol (hid_interface_protocol_enum_t)
  const char* protocol_str[] = {"None", "Keyboard", "Mouse"};
  uint8_t const itf_protocol = tuh_hid_interface_protocol(dev_addr, instance);

  hid_info[instance].report_count = tuh_hid_parse_report_descriptor(
      hid_info[instance].report_info, MAX_REPORT, desc_report, desc_len);
  log_line("%u reports", hid_info[instance].report_count);
  for (size_t i = 0; i < hid_info[instance].report_count; i++) {
    tuh_hid_report_info_t r = hid_info[instance].report_info[i];
    log_line("id: %u, page: %u, usage: %u", r.report_id, r.usage_page, r.usage);
  }

  uint16_t vid, pid;
  tuh_vid_pid_get(dev_addr, &vid, &pid);
  log_line("[%04x:%04x][%u] HID%u, proto=%s", vid, pid, dev_addr, instance,
           protocol_str[itf_protocol]);

  // Receive report from boot keyboard & mouse only
  // tuh_hid_report_received_cb() will be invoked when report is available
  if (itf_protocol == HID_ITF_PROTOCOL_KEYBOARD ||
      itf_protocol == HID_ITF_PROTOCOL_MOUSE) {
    active_device_type = itf_protocol;
    if (itf_protocol == HID_ITF_PROTOCOL_KEYBOARD) {
      official_kb_instance = instance;
      log_line("using instance %u for keyboard.", instance);
    } else if (itf_protocol == HID_ITF_PROTOCOL_MOUSE) {
      official_mouse_instance = instance;
      log_line("using instance %u for mouse.", instance);
    }
  }

  if (!tuh_hid_receive_report(dev_addr, instance)) {
    log_line("Error: cannot request report");
  }
}

// Invoked when device with hid interface is un-mounted
void tuh_hid_umount_cb(uint8_t dev_addr, uint8_t instance) {
  if (official_kb_instance == instance)
    official_kb_instance = NO_OFFICIAL_INSTANCE;
  if (official_mouse_instance == instance)
    official_mouse_instance = NO_OFFICIAL_INSTANCE;
  log_line("[%u] HID%u unmounted", dev_addr, instance);
}

static void process_kbd_report(uint8_t instance,
                               hid_keyboard_report_t const* report,
                               uint32_t time_ms) {
  if (official_kb_instance != NO_OFFICIAL_INSTANCE &&
      instance != official_kb_instance)
    return;
  active_device_type = HID_ITF_PROTOCOL_KEYBOARD;
  uint8_t slot = fx_enabled ? settings.getActiveFxSlot() : MAX_FX;
  keyboard_fx[slot]->process_keyboard_report((ha_keyboard_report_t*)report,
                                             time_ms);
}

// send mouse report to usb device CDC
static void process_mouse_report(uint8_t instance,
                                 hid_mouse_report_t const* report,
                                 uint32_t time_ms) {
  (void)time_ms;
  if (official_mouse_instance != NO_OFFICIAL_INSTANCE &&
      instance != official_mouse_instance)
    return;
  // buffer mouse updates to make sure they all get processed at a similar
  // sample rate
  active_device_type = HID_ITF_PROTOCOL_MOUSE;
  if (!mouse_report_ready) {
    pending_mouse_report.x = 0;
    pending_mouse_report.y = 0;
  }
  pending_mouse_report.x += report->x;
  pending_mouse_report.y += report->y;
  pending_mouse_report.buttons = report->buttons;
  pending_mouse_report.pan = report->pan;
  pending_mouse_report.wheel = report->wheel;
  mouse_report_ready = true;
}

inline uint8_t get_protocol_by_report_id(uint8_t id, uint8_t instance) {
  // find the tuh_hid_report_info_t that matches the id of the report we just
  // received
  for (size_t i = 0; i < hid_info[instance].report_count; i++) {
    tuh_hid_report_info_t info = hid_info[instance].report_info[i];
    if (info.report_id == id) {
      if (info.usage_page == GENERIC_DESKTOP_USAGE_PAGE) {
        if (info.usage == USAGE_MOUSE) {
          return HID_ITF_PROTOCOL_MOUSE;
        } else if (info.usage == USAGE_KEYBOARD) {
          return HID_ITF_PROTOCOL_KEYBOARD;
        }
      }
      // TODO handle other usage pages, Consumer Control, etc.
      break;
    }
  }
  return HID_ITF_PROTOCOL_NONE;
}

void tuh_hid_report_received_cb(uint8_t dev_addr, uint8_t instance,
                                uint8_t const* report, uint16_t len) {
  static char hid_log_buff[128];
  static uint32_t last_report_time = 0;
  uint32_t time_ms = MS_SINCE_BOOT;
  if (settings.areRawHidLogsEnabled()) {
    size_t log_i = sprintf(hid_log_buff, "id: %u, Δ: %lu, hid:", instance,
                           time_ms - last_report_time);
    for (size_t i = 0; i < len; i++) {
      log_i += sprintf(hid_log_buff + log_i, " %02x", report[i]);
    }
    log_line((const char*)hid_log_buff);
  }
  last_report_time = time_ms;

  uint8_t itf_protocol = HID_ITF_PROTOCOL_NONE;
  uint8_t const* report_offset = report;
  bool used_synthesized_report = false;

  if (instance == NO_OFFICIAL_INSTANCE) {
    used_synthesized_report = true;
    itf_protocol = HID_ITF_PROTOCOL_MOUSE;
  } else if (hid_info[instance].report_count > 2) {
    // HANDLE COMBINATION MOUSE/KEYBOARDS
    // I HAVE NO IDEA HOW UNIVERSAL THIS IS!
    // we know this is a composite report, so extract the id and start the
    // reading the data one byte over
    report_offset = report + 1;
    uint8_t id = report[0];
    itf_protocol = get_protocol_by_report_id(id, instance);
  } else {
    // TODO - can probably cache all this on mount/unmount
    itf_protocol = tuh_hid_interface_protocol(dev_addr, instance);
    // if we still don't know the protocol, and there's only one report, try to
    // use that as source of truth
    if (itf_protocol == HID_ITF_PROTOCOL_NONE &&
        hid_info[instance].report_count == 1) {
      itf_protocol = get_protocol_by_report_id(0, instance);
    }
  }

  switch (itf_protocol) {
    case HID_ITF_PROTOCOL_KEYBOARD:
      process_kbd_report(instance, (hid_keyboard_report_t const*)report_offset,
                         time_ms);
      break;

    case HID_ITF_PROTOCOL_MOUSE:
      process_mouse_report(instance, (hid_mouse_report_t const*)report_offset,
                           time_ms);
      break;

    default:
      break;
  }

  // continue to request to receive report
  if (!used_synthesized_report && !tuh_hid_receive_report(dev_addr, instance)) {
    log_line("Error: cannot request report");
  }
}

// process any report that does not come from a "real" mouse.
static void process_sidedoor_mouse_report(uint8_t buttons, int8_t x, int8_t y) {
  static hid_mouse_report_t report;
  report.buttons = buttons;
  report.x = x;
  report.y = y;
  tuh_hid_report_received_cb(0, NO_OFFICIAL_INSTANCE, (const uint8_t*)&report,
                             sizeof(report));
}

void tud_cdc_rx_cb(uint8_t itf) {
  (void)itf;
  if (tud_cdc_available()) {
    cdc_read_head += tud_cdc_read(cdc_read_buffer + cdc_read_head,
                                  LOG_BUFFER_SIZE - cdc_read_head);
  }
}

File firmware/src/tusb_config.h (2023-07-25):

/**
 * adapted from:
 * https://github.com/sekigon-gonnoc/Pico-PIO-USB/blob/main/examples/host_hid_to_device_cdc/tusb_config.h
 */

/*
 * The MIT License (MIT)
 *
 * Copyright (c) 2019 Ha Thach (tinyusb.org)
 *
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
 */

#ifndef _TUSB_CONFIG_H_
#define _TUSB_CONFIG_H_

#ifdef __cplusplus
extern "C" {
#endif

//--------------------------------------------------------------------+
// Board Specific Configuration
//--------------------------------------------------------------------+

// RHPort number used for device can be defined by board.mk, default to port 0
#ifndef BOARD_TUD_RHPORT
#define BOARD_TUD_RHPORT 0
#endif

// RHPort max operational speed can defined by board.mk
#ifndef BOARD_TUD_MAX_SPEED
#define BOARD_TUD_MAX_SPEED OPT_MODE_DEFAULT_SPEED
#endif

//--------------------------------------------------------------------
// COMMON CONFIGURATION
//--------------------------------------------------------------------

// defined by compiler flags for flexibility
#ifndef CFG_TUSB_MCU
#error CFG_TUSB_MCU must be defined
#endif

#define CFG_TUSB_OS OPT_OS_PICO

// Enable device stack
#define CFG_TUD_ENABLED 1

// Enable host stack with pio-usb if Pico-PIO-USB library is available
#define CFG_TUH_ENABLED 1
#define CFG_TUH_RPI_PIO_USB 1

// #ifndef CFG_TUSB_DEBUG
// #define CFG_TUSB_DEBUG        0
// #endif

// Default is max speed that hardware controller could support with on-chip PHY
#define CFG_TUD_MAX_SPEED BOARD_TUD_MAX_SPEED

/* USB DMA on some MCUs can only access a specific SRAM region with restriction
 * on alignment. Tinyusb use follows macros to declare transferring memory so
 * that they can be put into those specific section. e.g
 * - CFG_TUSB_MEM SECTION : __attribute__ (( section(".usb_ram") ))
 * - CFG_TUSB_MEM_ALIGN   : __attribute__ ((aligned(4)))
 */
#ifndef CFG_TUSB_MEM_SECTION
#define CFG_TUSB_MEM_SECTION
#endif

#ifndef CFG_TUSB_MEM_ALIGN
#define CFG_TUSB_MEM_ALIGN __attribute__((aligned(4)))
#endif

//--------------------------------------------------------------------
// DEVICE CONFIGURATION
//--------------------------------------------------------------------

#ifndef CFG_TUD_ENDPOINT0_SIZE
#define CFG_TUD_ENDPOINT0_SIZE 64
#endif

//------------- CLASS -------------//
#define CFG_TUD_HID 1
#define CFG_TUD_CDC 1
#define CFG_TUD_MSC 0
#define CFG_TUD_MIDI 0
#define CFG_TUD_VENDOR 0

// HID buffer size Should be sufficient to hold ID (if any) + Data
#define CFG_TUD_HID_EP_BUFSIZE 16
#define CFG_TUD_CDC_RX_BUFSIZE (TUD_OPT_HIGH_SPEED ? 512 : 64)
#define CFG_TUD_CDC_TX_BUFSIZE (TUD_OPT_HIGH_SPEED ? 512 : 64)

// CDC Endpoint transfer buffer size, more is faster
#define CFG_TUD_CDC_EP_BUFSIZE (TUD_OPT_HIGH_SPEED ? 512 : 64)

//--------------------------------------------------------------------
// HOST CONFIGURATION
//--------------------------------------------------------------------

// Size of buffer to hold descriptors and other data used for enumeration
#define CFG_TUH_ENUMERATION_BUFSIZE 256

#define CFG_TUH_HUB 1
// max device support (excluding hub device)
#define CFG_TUH_DEVICE_MAX (CFG_TUH_HUB ? 4 : 1)  // hub typically has 4 ports

#define CFG_TUH_HID 4
#define CFG_TUH_HID_EPIN_BUFSIZE 64
#define CFG_TUH_HID_EPOUT_BUFSIZE 64

#ifdef __cplusplus
}
#endif

#endif /* _TUSB_CONFIG_H_ */

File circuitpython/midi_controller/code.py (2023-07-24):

import board
import digitalio
from analogio import AnalogIn
import time
import neopixel
import microcontroller
import adafruit_midi
from adafruit_midi.control_change import ControlChange
import usb_midi

# Should work with HA boards with v >=cir 0.2

pixel = neopixel.NeoPixel(board.D3, 1, brightness=0.0, auto_write=False)

tgl0 = digitalio.DigitalInOut(board.D8)
tgl0.pull = digitalio.Pull.UP
tgl0_v = tgl0.value

tgl1 = digitalio.DigitalInOut(board.D7)
tgl1.pull = digitalio.Pull.UP
tgl1_v = tgl1.value

boot_btn = digitalio.DigitalInOut(board.D6)
boot_btn.pull = digitalio.Pull.UP

foot_sw = digitalio.DigitalInOut(board.A2)
foot_sw.pull = digitalio.Pull.UP
foot_sw_v = foot_sw.value

analog_in = AnalogIn(board.A0)
pot_v_9bit = analog_in.value >> 7
pot_v_7bit = pot_v_9bit >> 2
color_override = None

midi = adafruit_midi.MIDI(midi_in=usb_midi.ports[0], midi_out=usb_midi.ports[1],
                          out_channel=0)

while True:
    event = midi.receive()
    while isinstance(event, ControlChange):
        color_copy = color_override or [0,0,0]
        should_update = True
        if event.control == 110:
            color_copy[0] = event.value * 2
        elif event.control == 111:
            color_copy[1] = event.value * 2
        elif event.control == 112:
            color_copy[2] = event.value * 2
        else:
            should_update = False
        if should_update:
            print("UPDATED COLOR:",event, color_copy)
            color_override = color_copy
        event = midi.receive()
    if (not boot_btn.value):
        microcontroller.on_next_reset(microcontroller.RunMode.UF2)
        microcontroller.reset()
    if (tgl0.value != tgl0_v):
        tgl0_v = not tgl0_v
        midi.send(ControlChange(110, 0 if tgl0_v else 127))
        print("TGL0 switched:", tgl0_v)
    if (tgl1.value != tgl1_v):
        tgl1_v = not tgl1_v
        midi.send(ControlChange(111, 0 if tgl1_v else 127))
        print("TGL1 switched:", tgl1_v)
    if (foot_sw.value != foot_sw_v):
        foot_sw_v = not foot_sw_v
        midi.send(ControlChange(112, 0 if foot_sw_v else 127))
        print("FOOT_SW switched:", foot_sw_v)
    
    # take a few readings and average them for a tiny bit of filtering
    # analog_in.value is an unsigned, 16 bit value
    pot_readings = []
    pot_sample_count = 15
    for _ in range(pot_sample_count):
        pot_readings.append(analog_in.value >> 7)
        time.sleep(0.001)
    current_pot_v_9bit = round(sum(pot_readings) / pot_sample_count)
    # it tends to flicker between adjacent values, 
    # so safe to move forward once the value changes by a magnitude >= 3
    if (abs(current_pot_v_9bit - pot_v_9bit) >= 3):
        pot_v_9bit = current_pot_v_9bit
        current_pot_v_7bit = current_pot_v_9bit >> 2
        # avoid sending the same value twice
        if (current_pot_v_7bit != pot_v_7bit):
            pot_v_7bit = current_pot_v_7bit
            midi.send(ControlChange(113, pot_v_7bit))
            print("POT adjusted:", pot_v_7bit)

    r = 0 if tgl0_v else 255
    g = 0 if tgl1_v else 255
    b = 255 if foot_sw_v else 0
    pixel[0] = color_override or (r,g,b)

    pixel.brightness = 1.0 if color_override is not None else analog_in.value / 65536
    pixel.show()

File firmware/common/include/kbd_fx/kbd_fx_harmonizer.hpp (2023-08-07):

#include "custom_hid.hpp"
#include "hid_fx.hpp"

#define PRESSED_KEYS_COUNT REPORT_KEYCODE_COUNT / 2

class KeyboardHarmonizer : public IKeyboardFx {
  using IKeyboardFx::IKeyboardFx;
  uint8_t pressed_keys[PRESSED_KEYS_COUNT] = {0};
  uint8_t report_code_buffer[REPORT_KEYCODE_COUNT] = {0};
  uint8_t harmony_offset = 1;
  uint8_t harmonics = 0;
  uint8_t led_flash_count = 0;
  uint32_t last_flash_time = 0;
  float led_brightness = 0.3;

  int8_t index_of(uint8_t keycode, const uint8_t* array) {
    uint8_t n = sizeof(array);
    for (size_t i = 0; i < n; i++) {
      if (array[i] == keycode) {
        return i;
      }
    }
    return -1;
  }

  inline int8_t free_slot_index() { return index_of(0, pressed_keys); }

 public:

  void initialize(uint32_t time_ms, float param_percentage) {
    (void)time_ms;
    (void)param_percentage;
    log_line("Keyboard harmonizer initialized");
    update_parameter(param_percentage);
  }

  uint32_t get_current_pixel_value(uint32_t time_ms) {
    if (led_flash_count == 0 || time_ms - last_flash_time < 32) {
      return color_at_brightness(indicator_color, led_brightness);
    }
    last_flash_time = time_ms;
    led_flash_count--;
    if (led_flash_count & 1) {
      return color_at_brightness(indicator_color, 0.1f);
    } else {
      return color_at_brightness(indicator_color, 0.8f);
    }
  }

  void update_parameter(float percentage) {
    uint8_t raw_percentage = (uint8_t)(percentage * 98.0);
    harmony_offset = raw_percentage % 33;
    uint8_t last_harmonic_value = harmonics;
    harmonics = raw_percentage / 33;
    // if we cross into a new zone, defined by the number of harmonics, flash to
    // let user know
    if (last_harmonic_value != harmonics) {
      led_flash_count = (2 * harmonics) + 2;
      log_line("Keyboard harmonics: %u", harmonics);
    }
    led_brightness = (((float)harmony_offset / 33.0) * 0.8) + 0.05;
  }

  void tick(uint32_t time_ms) { (void)time_ms; }

  void deinit() {}

  void process_keyboard_report(ha_keyboard_report_t const* report,
                               uint32_t time_ms) {
    (void)time_ms;
    for (size_t i = 0; i < REPORT_KEYCODE_COUNT; i++) {
      uint8_t keycode = report->keycode[i];
      if (keycode == 0) break;
      int8_t free_slot = free_slot_index();
      if (free_slot < 0) break;
      int8_t pressed_key_index = index_of(keycode, pressed_keys);
      if (pressed_key_index < 0) {
        pressed_keys[free_slot] = keycode;
      }
    }

    for (size_t i = 0; i < PRESSED_KEYS_COUNT; i++) {
      int8_t currently_pressed_index =
          index_of(pressed_keys[i], report->keycode);
      if (currently_pressed_index == -1) {
        pressed_keys[i] = 0;
      }
    }

    size_t j = 0;
    for (size_t i = 0; i < PRESSED_KEYS_COUNT && j < REPORT_KEYCODE_COUNT;
         i++) {
      uint8_t pressed_key = pressed_keys[i];
      if (pressed_key > 0) {
        if (harmonics == 0) {
          // execute one key press
          report_code_buffer[j++] = pressed_key + harmony_offset;
          led_flash_count = 3;
        } else {
          // execute two keys
          led_flash_count = 5;
          report_code_buffer[j++] = pressed_key;
          report_code_buffer[j++] = pressed_key + harmony_offset;
          // execute three keys
          if (harmonics == 2) {
            report_code_buffer[j++] = pressed_key + (harmony_offset * 2);
            led_flash_count = 7;
          }
        }
      }
    }

    while (j < REPORT_KEYCODE_COUNT) {
      report_code_buffer[j] = 0;
      ++j;
    }
    hid_output->send_keyboard_report(report->modifier, report->reserved,
                         report_code_buffer);
  }
};

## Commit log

2023-03-29 test sarcastic mode, fix dead zone for mode switching
    [mouse_fx_fuzz.hpp]
2023-05-15 add eeprom persistence for board V2
2023-06-07 use pico pio lib from env variable, specify USB pin in application code
2023-06-13 add reboot and brightness commands to repl
    [hidden_agenda.cpp]
2023-07-19 add ability to change led colors to repl
2023-07-20 add option to reset to default settings
    [i2c_persistence.cpp, main.cpp]
2023-07-24 add circuitpython examples and docs
2023-07-26 add setting for led flashing, add led pattern for kbd xover
2023-07-28 add led pattern for mouse looping
2023-08-03 add hardware files for rev3
    [hidden_agenda.kicad_pcb, hidden_agenda.kicad_sch]
2023-08-03 hardware/enclosure source files
2023-08-03 hardware assembly notes
2023-08-03 usb jack cap docs
    [usb_caps_v6.stl]
2023-08-04 properly add xosc startup value to board def
2023-08-17 fix mouse accumulation, up version number
    [hidden_agenda.cpp]
2023-09-07 fix issue for devices that send multiple reports for keeb/mouse
    [hidden_agenda.cpp]
